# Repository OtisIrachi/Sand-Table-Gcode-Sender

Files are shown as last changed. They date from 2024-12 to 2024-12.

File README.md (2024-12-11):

****************************************************************************************************
Sand Table Gcode Sender

 Completed Table

This project is a mashup of several programs to create yet another version of a COREXY Sand Table.
My frustration was in the complexity of other projects, although done quite well,
but I wanted a simpler approach.  
Utilizes an ESP32 D1 Mini module as a "gcode sender" via the secondary Serial TX-Rx Port (pins 16 and 17)
to a modified Grbl CNC Shield UNO controller.
A logic level shifter board is needed to connect the 3.3V TX and RX from the ESP32 to the
5.0V TX and RX on the CNC Shield.
All files from this project are included.

Board Mount

Basic components are:

525mm x 525mm CoreXY Table.

Grbl CNC Shield and Arduino UNO for stepper motor controller.

TMC2209 Stepper Drivers for quiet operation.

ESP32 and SDCard module for sending gcode programs to the grbl stepper motor controller.

cnc shield and esp32 sender

****************************************************************************************************

The original STL Files are referenced from https://www.instructables.com/Easily-Build-a-MACHINE-THAT-DESTROYS-WHAT-IT-CREAT/  project.

The STL Files in this project folder were modified and used here:  

https://github.com/OtisIrachi/Sand-Table-Gcode-Sender/tree/main/Kinetic%20STL%20Files

The grbl source code is a modified version of the original V1.1 grbl source code found here:

https://github.com/OtisIrachi/Sand-Table-Gcode-Sender/tree/main/grbl_Modified

That source code is attached in this project.  All you need to do is load it onto your Arduino UNO.
Mostly it is changed for IO config and a Baud rate of 9600 in order to keep up with
motor moves and grbl handshaking.

****************************************************************************************************

The sand patterns were created with:

[https://github.com/markroland/sand-table-pattern-maker.](https://github.com/OtisIrachi/Sand-Table-Gcode-Sender/tree/main/SandPatternMaker525)

You may also use sandify.org:

https://sandify.org/

Each .gcode file is manually edited at beginning and the end for simplicity in the gsender coding. 

All comments created by Sand Table Maker or sandify.org
are deleted and an Fxxxx speed command is added to the first G1 line, and an "M2"
command at the end of each gcode file.

I modified the "env.js in the "SandPatternMaker525\assets\js" folder to match the 
dimensions of my sand table, roughly 525mm x 525mm.
Run the SandPatternMaker525 program by clicking on the "index.html" file.  It runs in your browser.

ex: 

G1 X5.000 Y5.000 F6000

G1 X12.728 Y0.000

G1 X0.000 Y12.728

G1 X0.000 Y25.456.....

M2

****************************************************************************************************
Table Lighting.

The LED Strip Controller uses an ESP8266 D1 Mini Module,  
a 30 LED/meter strip, 
and a Rotary Encoder Module with Push Button.

https://github.com/OtisIrachi/Sand-Table-Gcode-Sender/tree/main/ESPEncoderNeopixel.
LED Strip Controller

****************************************************************************************************

Wiring and Schematics for this project found here: 

https://github.com/OtisIrachi/Sand-Table-Gcode-Sender/tree/main/Schematics

****************************************************************************************************

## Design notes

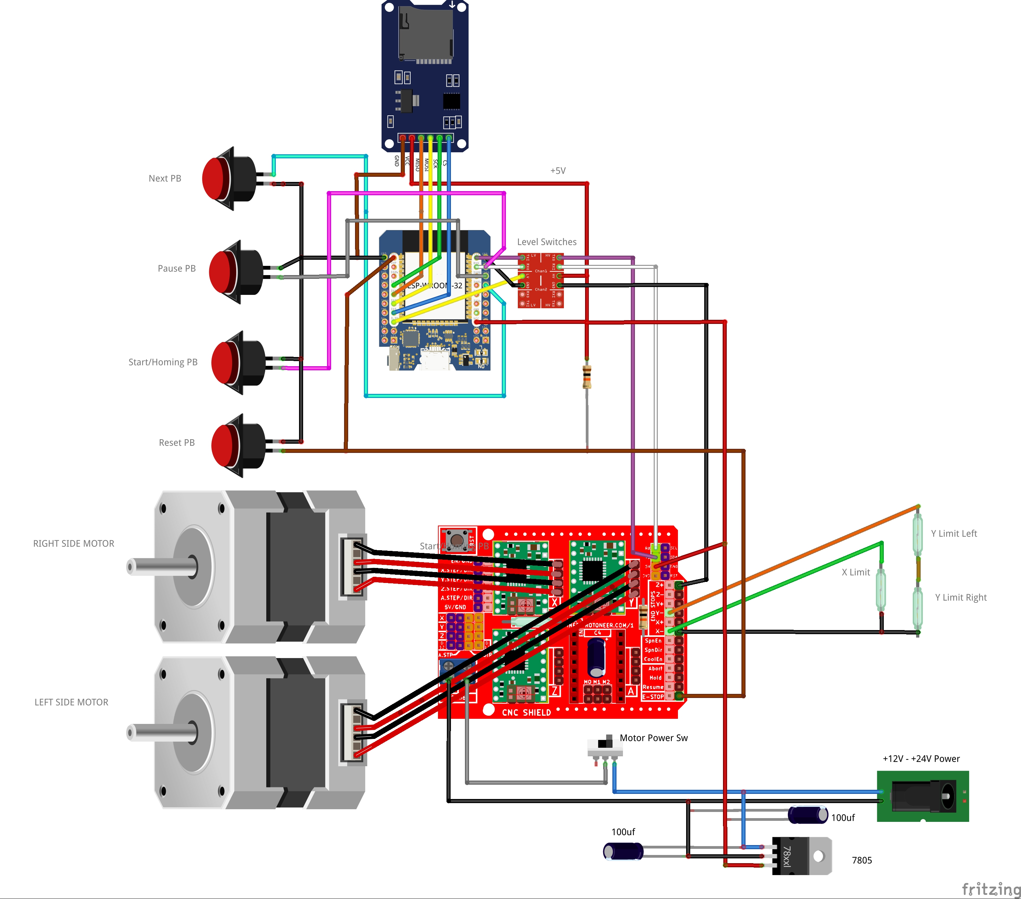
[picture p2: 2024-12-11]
Schematics/GcodeSenderESP32_Fritz.jpg

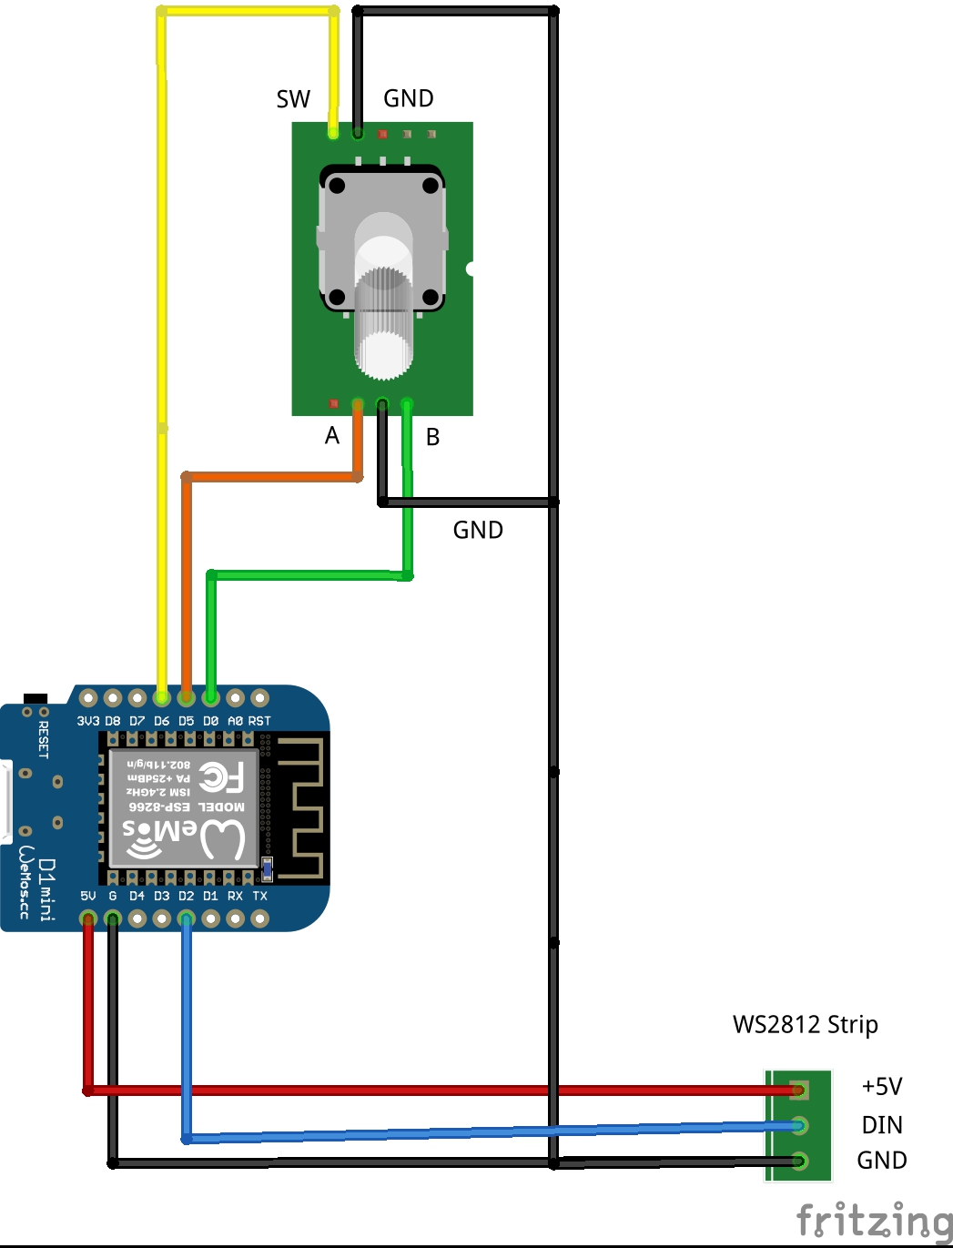
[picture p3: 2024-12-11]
Schematics/ESPEncoderNeopixel_Fritz.jpg

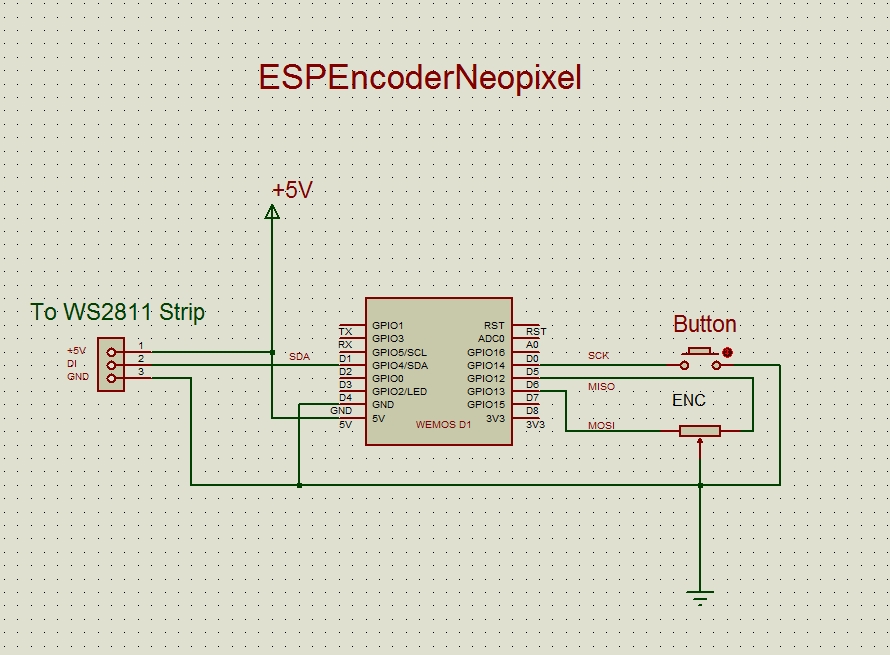
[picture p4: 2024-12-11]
Schematics/LED Strip Controller.jpg

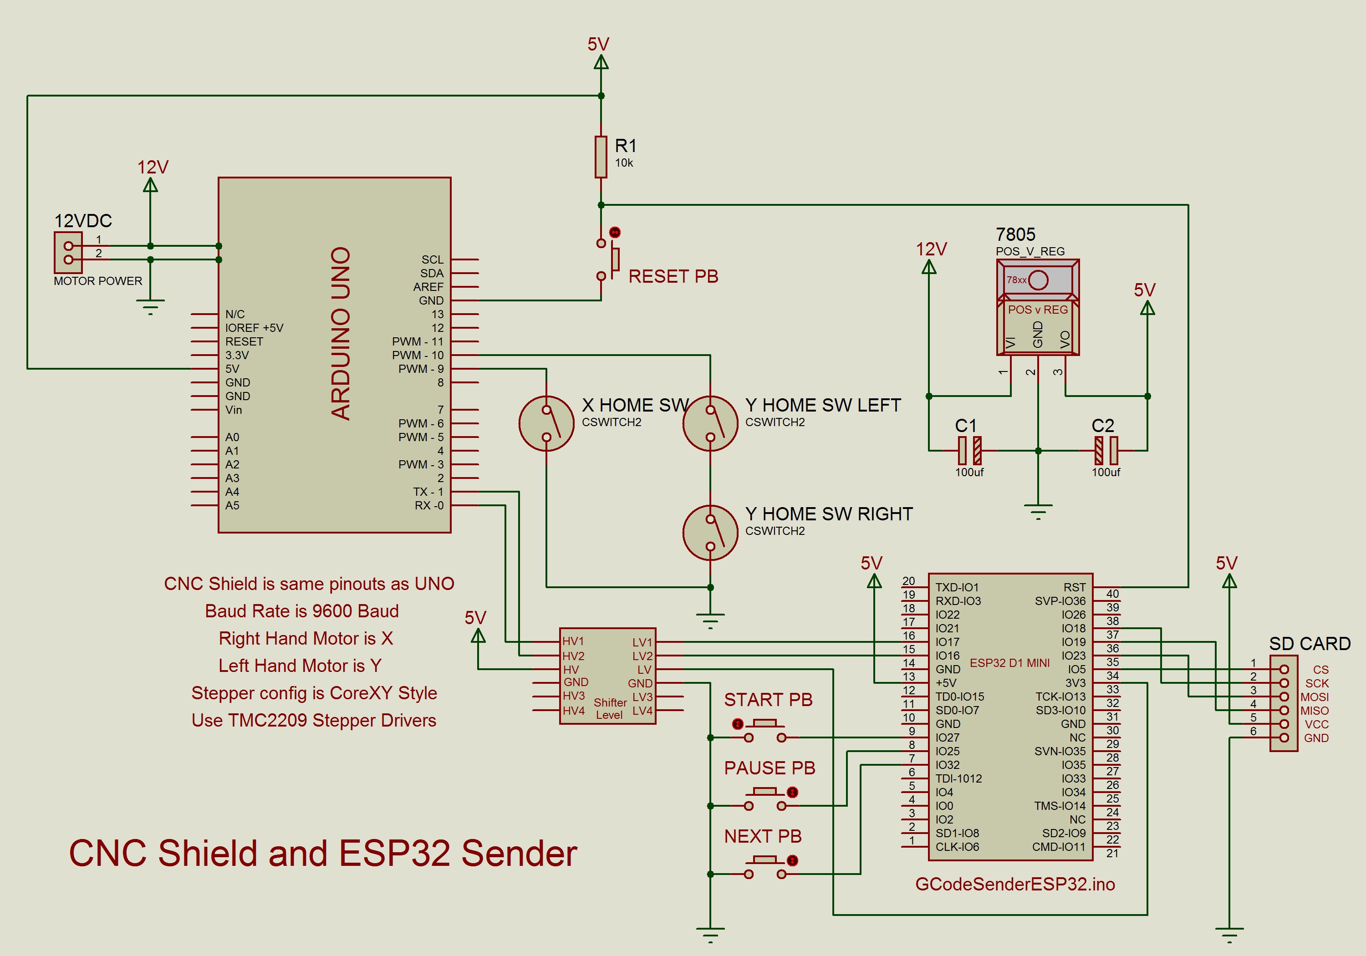
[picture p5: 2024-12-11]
Schematics/cnc shield and esp32 sender.jpg

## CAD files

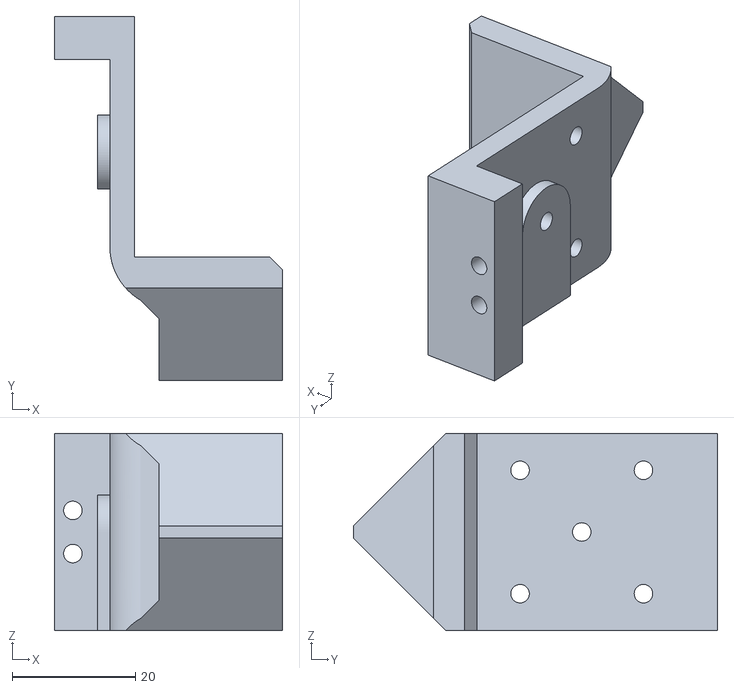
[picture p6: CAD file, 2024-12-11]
Kinetic STL Files/MagnetMount.stl
37.0 x 59.0 x 32.0

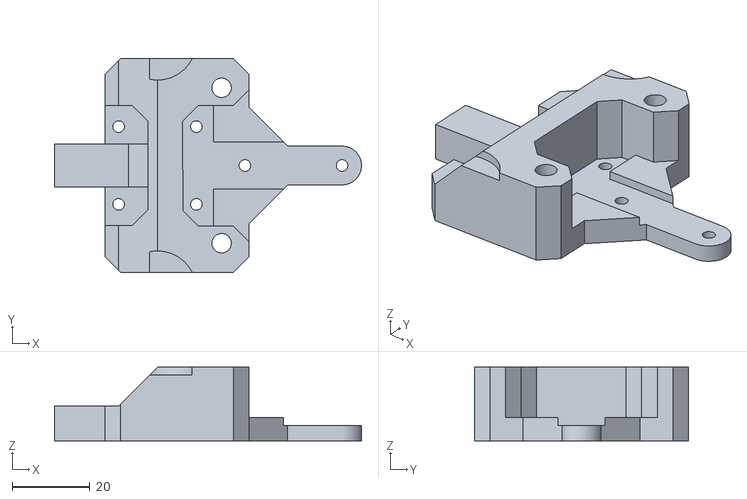
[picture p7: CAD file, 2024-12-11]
Kinetic STL Files/X-CarriageMount.stl
79.0 x 55.0 x 19.0

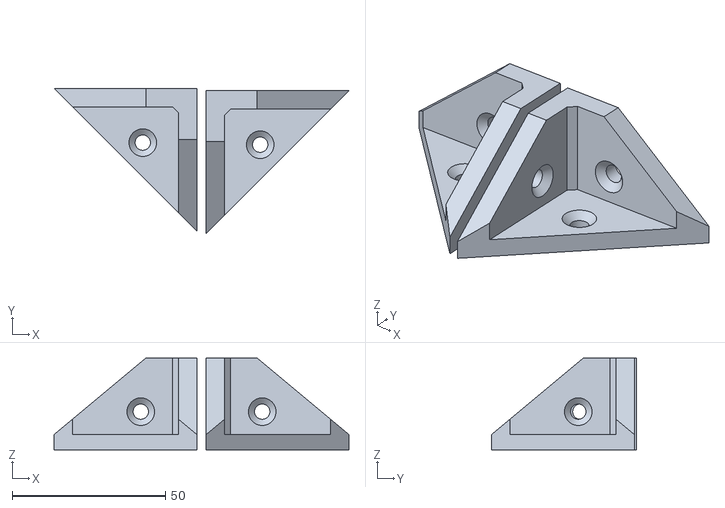
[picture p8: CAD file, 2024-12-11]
Kinetic STL Files/Corner Brackets Pair.stl
96.3 x 47.4 x 30.0

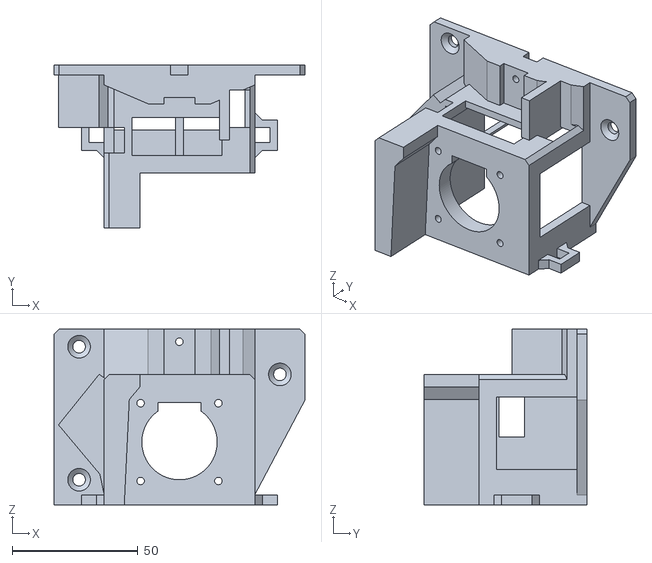
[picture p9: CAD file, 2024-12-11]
Kinetic STL Files/MotorBaseRight.stl
100.0 x 65.0 x 70.0

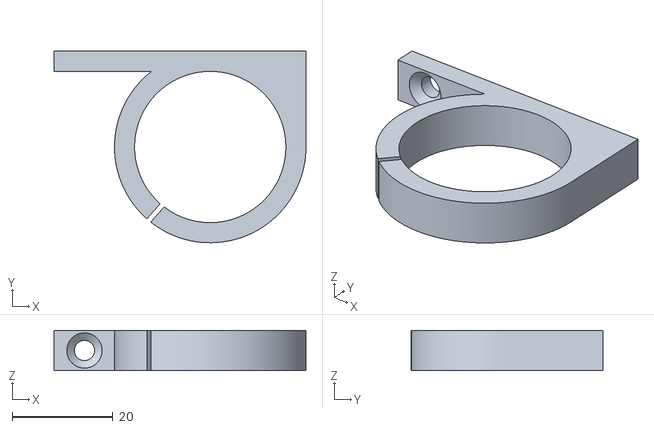
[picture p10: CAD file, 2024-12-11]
Kinetic STL Files/WireLoop.stl
50.0 x 38.0 x 8.00

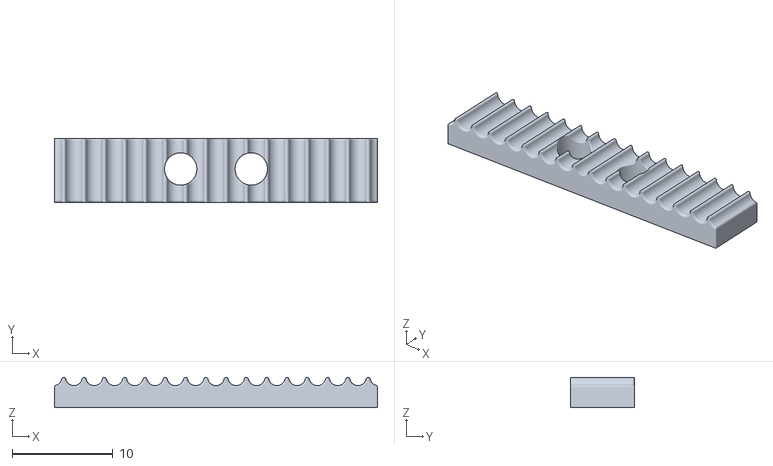
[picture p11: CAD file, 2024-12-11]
Kinetic STL Files/BeltGrip.stl
32.0 x 6.30 x 3.00

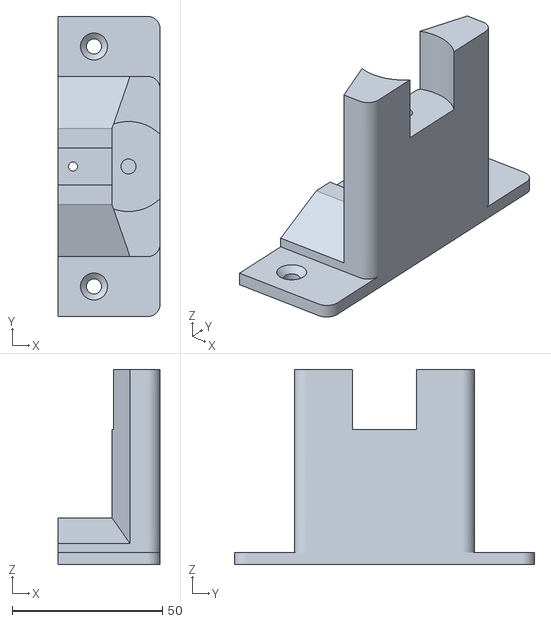
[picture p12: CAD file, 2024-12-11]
Kinetic STL Files/IdleSupport.stl
34.0 x 100.0 x 65.0

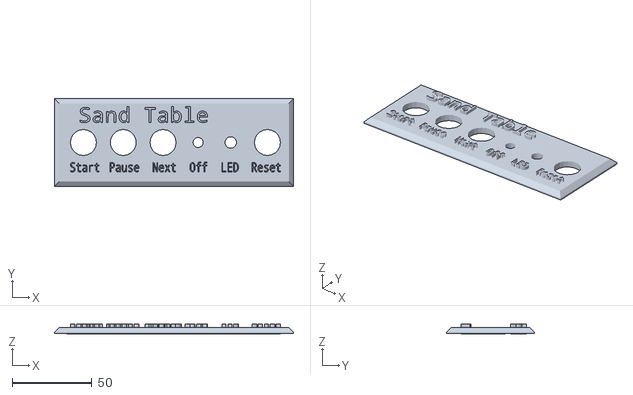
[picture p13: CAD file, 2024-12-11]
Kinetic STL Files/My Control Panel.stl
150.0 x 55.0 x 6.00

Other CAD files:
Kinetic STL Files/MotorBaseLeft.stl

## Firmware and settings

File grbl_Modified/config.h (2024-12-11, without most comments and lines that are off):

#define config_h
#include "grbl.h" // For Arduino IDE compatibility.
#define DEFAULTS_DIYM_SAND_TABLE
#define CPU_MAP_ATMEGA328P // Arduino Uno CPU
#define BAUD_RATE 9600
#define CMD_RESET 0x18 // ctrl-x.
#define CMD_STATUS_REPORT '?'
#define CMD_CYCLE_START '~'
#define CMD_FEED_HOLD '!'
#define CMD_SAFETY_DOOR 0x84
#define CMD_JOG_CANCEL  0x85
#define CMD_DEBUG_REPORT 0x86 // Only when DEBUG enabled, sends debug report in '{}' braces.
#define CMD_FEED_OVR_RESET 0x90         // Restores feed override value to 100%.
#define CMD_FEED_OVR_COARSE_PLUS 0x91
#define CMD_FEED_OVR_COARSE_MINUS 0x92
#define CMD_FEED_OVR_FINE_PLUS  0x93
#define CMD_FEED_OVR_FINE_MINUS  0x94
#define CMD_RAPID_OVR_RESET 0x95        // Restores rapid override value to 100%.
#define CMD_RAPID_OVR_MEDIUM 0x96
#define CMD_RAPID_OVR_LOW 0x97
#define CMD_SPINDLE_OVR_RESET 0x99      // Restores spindle override value to 100%.
#define CMD_SPINDLE_OVR_COARSE_PLUS 0x9A
#define CMD_SPINDLE_OVR_COARSE_MINUS 0x9B
#define CMD_SPINDLE_OVR_FINE_PLUS 0x9C
#define CMD_SPINDLE_OVR_FINE_MINUS 0x9D
#define CMD_SPINDLE_OVR_STOP 0x9E
#define CMD_COOLANT_FLOOD_OVR_TOGGLE 0xA0
#define CMD_COOLANT_MIST_OVR_TOGGLE 0xA1
 #define HOMING_CYCLE_0 (1<<Y_AXIS)  // COREXY COMPATIBLE: First home Y
 #define HOMING_CYCLE_1 (1<<X_AXIS)  // COREXY COMPATIBLE: Then home X
#define N_HOMING_LOCATE_CYCLE 1 // Integer (1-128)
#define HOMING_FORCE_SET_ORIGIN // Uncomment to enable.
#define N_STARTUP_LINE 2 // Integer (1-2)
#define N_DECIMAL_COORDVALUE_INCH 4 // Coordinate or position value in inches
#define N_DECIMAL_COORDVALUE_MM   3 // Coordinate or position value in mm
#define N_DECIMAL_RATEVALUE_INCH  1 // Rate or velocity value in in/min
#define N_DECIMAL_RATEVALUE_MM    0 // Rate or velocity value in mm/min
#define N_DECIMAL_SETTINGVALUE    3 // Decimals for floating point setting values
#define N_DECIMAL_RPMVALUE        0 // RPM value in rotations per min.
#define MESSAGE_PROBE_COORDINATES // Enabled by default. Comment to disable.
#define SAFETY_DOOR_SPINDLE_DELAY 4.0 // Float (seconds)
#define SAFETY_DOOR_COOLANT_DELAY 1.0 // Float (seconds)
 #define COREXY // Default disabled. Uncomment to enable.
#define CHECK_LIMITS_AT_INIT
#define DEFAULT_FEED_OVERRIDE           100 // 100%. Don't change this value.
#define MAX_FEED_RATE_OVERRIDE          200 // Percent of programmed feed rate (100-255). Usually 120% or 200%
#define MIN_FEED_RATE_OVERRIDE           10 // Percent of programmed feed rate (1-100). Usually 50% or 1%
#define FEED_OVERRIDE_COARSE_INCREMENT   10 // (1-99). Usually 10%.
#define FEED_OVERRIDE_FINE_INCREMENT      1 // (1-99). Usually 1%.
#define DEFAULT_RAPID_OVERRIDE  100 // 100%. Don't change this value.
#define RAPID_OVERRIDE_MEDIUM    50 // Percent of rapid (1-99). Usually 50%.
#define RAPID_OVERRIDE_LOW       25 // Percent of rapid (1-99). Usually 25%.
#define DEFAULT_SPINDLE_SPEED_OVERRIDE    100 // 100%. Don't change this value.
#define MAX_SPINDLE_SPEED_OVERRIDE        200 // Percent of programmed spindle speed (100-255). Usually 200%.
#define MIN_SPINDLE_SPEED_OVERRIDE         10 // Percent of programmed spindle speed (1-100). Usually 10%.
#define SPINDLE_OVERRIDE_COARSE_INCREMENT  10 // (1-99). Usually 10%.
#define SPINDLE_OVERRIDE_FINE_INCREMENT     1 // (1-99). Usually 1%.
#define RESTORE_OVERRIDES_AFTER_PROGRAM_END // Default enabled. Comment to disable.
#define REPORT_FIELD_BUFFER_STATE // Default enabled. Comment to disable.
#define REPORT_FIELD_PIN_STATE // Default enabled. Comment to disable.
#define REPORT_FIELD_CURRENT_FEED_SPEED // Default enabled. Comment to disable.
#define REPORT_FIELD_WORK_COORD_OFFSET // Default enabled. Comment to disable.
#define REPORT_FIELD_OVERRIDES // Default enabled. Comment to disable.
#define REPORT_FIELD_LINE_NUMBERS // Default enabled. Comment to disable.
#define REPORT_OVR_REFRESH_BUSY_COUNT 20  // (1-255)
#define REPORT_OVR_REFRESH_IDLE_COUNT 10  // (1-255) Must be less than or equal to the busy count
#define REPORT_WCO_REFRESH_BUSY_COUNT 30  // (2-255)
#define REPORT_WCO_REFRESH_IDLE_COUNT 10  // (2-255) Must be less than or equal to the busy count
#define ACCELERATION_TICKS_PER_SECOND 100
#define ADAPTIVE_MULTI_AXIS_STEP_SMOOTHING  // Default enabled. Comment to disable.
#define TOOL_LENGTH_OFFSET_AXIS Z_AXIS // Default z-axis. Valid values are X_AXIS, Y_AXIS, or Z_AXIS.
#define VARIABLE_SPINDLE // Default enabled. Comment to disable.
#define MINIMUM_JUNCTION_SPEED 0.0 // (mm/min)
#define MINIMUM_FEED_RATE 1.0 // (mm/min)
#define N_ARC_CORRECTION 12 // Integer (1-255)
#define ARC_ANGULAR_TRAVEL_EPSILON 5E-7 // Float (radians)
#define DWELL_TIME_STEP 50 // Integer (1-255) (milliseconds)
#define ENABLE_RESTORE_EEPROM_WIPE_ALL         // '$RST=*' Default enabled. Comment to disable.
#define ENABLE_RESTORE_EEPROM_DEFAULT_SETTINGS // '$RST=$' Default enabled. Comment to disable.
#define ENABLE_RESTORE_EEPROM_CLEAR_PARAMETERS // '$RST=#' Default enabled. Comment to disable.
#define ENABLE_BUILD_INFO_WRITE_COMMAND // '$I=' Default enabled. Comment to disable.
#define FORCE_BUFFER_SYNC_DURING_EEPROM_WRITE // Default enabled. Comment to disable.
#define FORCE_BUFFER_SYNC_DURING_WCO_CHANGE // Default enabled. Comment to disable.
#define PARKING_AXIS Z_AXIS // Define which axis that performs the parking motion
#define PARKING_TARGET -5.0 // Parking axis target. In mm, as machine coordinate [-max_travel,0].
#define PARKING_RATE 500.0 // Parking fast rate after pull-out in mm/min.
#define PARKING_PULLOUT_RATE 100.0 // Pull-out/plunge slow feed rate in mm/min.
#define PARKING_PULLOUT_INCREMENT 5.0 // Spindle pull-out and plunge distance in mm. Incremental distance.
#define DISABLE_LASER_DURING_HOLD // Default enabled. Comment to disable.
#define N_PIECES 4  // Integer (1-4). Number of piecewise lines used in script solution.
#define RPM_MAX  11686.4  // Max RPM of model. $30 > RPM_MAX will be limited to RPM_MAX.
#define RPM_MIN  202.5    // Min RPM of model. $31 < RPM_MIN will be limited to RPM_MIN.
#define RPM_POINT12  6145.4  // Used N_PIECES >=2. Junction point between lines 1 and 2.
#define RPM_POINT23  9627.8  // Used N_PIECES >=3. Junction point between lines 2 and 3.
#define RPM_POINT34  10813.9 // Used N_PIECES = 4. Junction point between lines 3 and 4.
#define RPM_LINE_A1  3.197101e-03  // Used N_PIECES >=1. A and B constants of line 1.
#define RPM_LINE_B1  -3.526076e-1
#define RPM_LINE_A2  1.722950e-2   // Used N_PIECES >=2. A and B constants of line 2.
#define RPM_LINE_B2  8.588176e+01
#define RPM_LINE_A3  5.901518e-02  // Used N_PIECES >=3. A and B constants of line 3.
#define RPM_LINE_B3  4.881851e+02
#define RPM_LINE_A4  1.203413e-01  // Used N_PIECES = 4. A and B constants of line 4.
#define RPM_LINE_B4  1.151360e+03
#define DUAL_AXIS_SELECT  X_AXIS  // Must be either X_AXIS or Y_AXIS
#define DUAL_AXIS_HOMING_FAIL_AXIS_LENGTH_PERCENT  5.0  // Float (percent)
#define DUAL_AXIS_HOMING_FAIL_DISTANCE_MAX  25.0  // Float (mm)
#define DUAL_AXIS_HOMING_FAIL_DISTANCE_MIN  2.5  // Float (mm)
#define DUAL_AXIS_CONFIG_PROTONEER_V3_51    // Uncomment to select. Comment other configs.

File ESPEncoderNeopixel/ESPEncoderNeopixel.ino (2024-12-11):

//************************************************************************************************
// ESPEncoderNeopixel.ino
// Uses an ESP CPU and an Encode with switch to run through LED programs.
//
// Button = SCK
// Yellow = MOSI
// Orange = MISO 
// Led Strip IO33
//
//
// RCI 10-30-2024
//************************************************************************************************
#include <AiEsp32RotaryEncoder.h>
#include <Adafruit_NeoPixel.h>
#include "WS2811_Patterns.h"

#define pinPullups 0    // 0 = Pullup, 1 = PullDown

#if defined(ESP32)
#define ROTARY_ENCODER_A_PIN      25  // MISO
#define ROTARY_ENCODER_B_PIN      27  // MOSI
#define ROTARY_ENCODER_BUTTON_PIN 26  // SCK
#endif

#if defined(ESP8266)
#define ROTARY_ENCODER_A_PIN      13  // MISO
#define ROTARY_ENCODER_B_PIN      12  // MOSI
#define ROTARY_ENCODER_BUTTON_PIN 14  // SCK
#endif

#define ROTARY_ENCODER_STEPS 4


unsigned long time_now = 0;
int brightness = 127;
int progNum = 0;
//extern bool buttonPressedFlag = 0;

AiEsp32RotaryEncoder rotaryEncoder = AiEsp32RotaryEncoder(ROTARY_ENCODER_A_PIN, ROTARY_ENCODER_B_PIN, 
                                     ROTARY_ENCODER_BUTTON_PIN, -1, ROTARY_ENCODER_STEPS, pinPullups);
//******************************************************************************************
void IRAM_ATTR readEncoderISR()
{
    rotaryEncoder.readEncoder_ISR();
}
//************************************************************************************************
// Delay (loops) Milliseconds
void delayms(int loops) 
{
    time_now = millis();
    
    while(millis() < time_now + loops)
      {
      brightness = rotaryEncoder.readEncoder();
      strip.setBrightness(brightness);
      //Serial.println(rotaryEncoder.readEncoder());

      if (rotaryEncoder.isEncoderButtonClicked())
        {
        //Serial.println("button pressed");
        buttonPressedFlag = 1;
        progNum++;
        //break;
        }
      delay(1);   
      } 
           
}
//******************************************************************************************
void setup()
{
    Serial.begin(115200);
    delay(3000);
    pinMode(PIN, OUTPUT);
    
    rotaryEncoder.begin();
    //rotaryEncoder.areEncoderPinsPulldownforEsp32 = false;
    rotaryEncoder.setup(readEncoderISR);
    rotaryEncoder.setBoundaries(0, 255, false); 
    rotaryEncoder.setAcceleration(250);
    brightness = rotaryEncoder.readEncoder();
    progNum = 0;
   
}
//******************************************************************************************
void loop()
{

    
    if(progNum > 11) progNum = 0;

    switch(progNum)
       {
       case 0:
       SolidColor(wht, 1);
       delayms(1);
       break;
       //****************************
       case 1:
       SolidColor(rde, 1);
       delayms(1);
       break;
       //****************************
       case 2:
       SolidColor(grn, 1);
       delayms(1);
       break;
       //****************************
       case 3:
       SolidColor(blu, 1);
       delayms(1);
       break;
       //****************************
       case 4:
       SolidColor(yellow, 1);
       delayms(1);
       break;
       //****************************
       case 5:
       SolidColor(magenta, 1);
       delayms(1);
       break;
       //****************************
       case 6:
       SolidColor(cyan, 1);
       delayms(1);
       break;
       //****************************
       case 7:

       //theaterChaseRainbowFor(3, 1, 150); //  fixed rainbow color with chased position
       theaterChaseRainbow(3, 1, 150); // skipt, cycles, wait

       break;
       //****************************
       case 8:

       rainbowStrip(25);   // delay

       break;
       //****************************
       case 9:

       rainbowCycleFor(1, 25); 

       break;
       //****************************
       case 10:
       MultiCometRev(wht, 15, 1, 100);  // skipt, cycles, wait 
       delayms(1);
       break;
       //****************************
       case 11:

       RandomColorStrip(2, 1, 350); 

       break;                     
       //****************************
       default:

       break;       
       }



      


}
//******************************************************************************************

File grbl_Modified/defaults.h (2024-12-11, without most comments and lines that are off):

#ifdef DEFAULTS_GENERIC
  #define DEFAULT_X_STEPS_PER_MM 250.0
  #define DEFAULT_Y_STEPS_PER_MM 250.0
  #define DEFAULT_Z_STEPS_PER_MM 250.0
  #define DEFAULT_X_MAX_RATE 500.0 // mm/min
  #define DEFAULT_Y_MAX_RATE 500.0 // mm/min
  #define DEFAULT_Z_MAX_RATE 500.0 // mm/min
  #define DEFAULT_X_ACCELERATION (10.0*60*60) // 10*60*60 mm/min^2 = 10 mm/sec^2
  #define DEFAULT_Y_ACCELERATION (10.0*60*60) // 10*60*60 mm/min^2 = 10 mm/sec^2
  #define DEFAULT_Z_ACCELERATION (10.0*60*60) // 10*60*60 mm/min^2 = 10 mm/sec^2
  #define DEFAULT_X_MAX_TRAVEL 200.0 // mm NOTE: Must be a positive value.
  #define DEFAULT_Y_MAX_TRAVEL 200.0 // mm NOTE: Must be a positive value.
  #define DEFAULT_Z_MAX_TRAVEL 200.0 // mm NOTE: Must be a positive value.
  #define DEFAULT_SPINDLE_RPM_MAX 1000.0 // rpm
  #define DEFAULT_SPINDLE_RPM_MIN 0.0 // rpm
  #define DEFAULT_STEP_PULSE_MICROSECONDS 10
  #define DEFAULT_STEPPING_INVERT_MASK 0
  #define DEFAULT_DIRECTION_INVERT_MASK 0
  #define DEFAULT_STEPPER_IDLE_LOCK_TIME 25 // msec (0-254, 255 keeps steppers enabled)
  #define DEFAULT_STATUS_REPORT_MASK 1 // MPos enabled
  #define DEFAULT_JUNCTION_DEVIATION 0.01 // mm
  #define DEFAULT_ARC_TOLERANCE 0.002 // mm
  #define DEFAULT_REPORT_INCHES 0 // false
  #define DEFAULT_INVERT_ST_ENABLE 0 // false
  #define DEFAULT_INVERT_LIMIT_PINS 0 // false
  #define DEFAULT_SOFT_LIMIT_ENABLE 0 // false
  #define DEFAULT_HARD_LIMIT_ENABLE 0  // false
  #define DEFAULT_INVERT_PROBE_PIN 0 // false
  #define DEFAULT_LASER_MODE 0 // false
  #define DEFAULT_HOMING_ENABLE 0  // false
  #define DEFAULT_HOMING_DIR_MASK 0 // move positive dir
  #define DEFAULT_HOMING_FEED_RATE 25.0 // mm/min
  #define DEFAULT_HOMING_SEEK_RATE 500.0 // mm/min
  #define DEFAULT_HOMING_DEBOUNCE_DELAY 250 // msec (0-65k)
  #define DEFAULT_HOMING_PULLOFF 1.0 // mm
#endif
  #define DEFAULT_X_STEPS_PER_MM 80.0
  #define DEFAULT_Y_STEPS_PER_MM 80.0
  #define DEFAULT_Z_STEPS_PER_MM 250.0
  #define DEFAULT_X_MAX_RATE 5000.0 // mm/min
  #define DEFAULT_Y_MAX_RATE 5000.0 // mm/min
  #define DEFAULT_Z_MAX_RATE 250.0 // mm/min
  #define DEFAULT_X_ACCELERATION (50.0*60*60) // 10*60*60 mm/min^2 = 10 mm/sec^2
  #define DEFAULT_Y_ACCELERATION (50.0*60*60) // 10*60*60 mm/min^2 = 10 mm/sec^2
  #define DEFAULT_Z_ACCELERATION (10.0*60*60) // 10*60*60 mm/min^2 = 10 mm/sec^2
  #define DEFAULT_X_MAX_TRAVEL 500.0 // mm NOTE: Must be a positive value.
  #define DEFAULT_Y_MAX_TRAVEL 500.0 // mm NOTE: Must be a positive value.
  #define DEFAULT_Z_MAX_TRAVEL 200.0 // mm NOTE: Must be a positive value.
  #define DEFAULT_SPINDLE_RPM_MAX 1000.0 // rpm
  #define DEFAULT_SPINDLE_RPM_MIN 0.0 // rpm
  #define DEFAULT_STEP_PULSE_MICROSECONDS 10
  #define DEFAULT_STEPPING_INVERT_MASK 0
  #define DEFAULT_DIRECTION_INVERT_MASK 0
  #define DEFAULT_STEPPER_IDLE_LOCK_TIME 25 // msec (0-254, 255 keeps steppers enabled)
  #define DEFAULT_STATUS_REPORT_MASK 1 // MPos enabled
  #define DEFAULT_JUNCTION_DEVIATION 0.01 // mm
  #define DEFAULT_ARC_TOLERANCE 0.002 // mm
  #define DEFAULT_REPORT_INCHES 0 // false
  #define DEFAULT_INVERT_ST_ENABLE 0 // false
  #define DEFAULT_INVERT_LIMIT_PINS 0 // false
  #define DEFAULT_SOFT_LIMIT_ENABLE 0 // true
  #define DEFAULT_HARD_LIMIT_ENABLE 1  // true
  #define DEFAULT_INVERT_PROBE_PIN 0 // false
  #define DEFAULT_LASER_MODE 0 // false
  #define DEFAULT_HOMING_ENABLE 1  // true
  #define DEFAULT_HOMING_DIR_MASK 3 // move positive dir
  #define DEFAULT_HOMING_FEED_RATE 25.0 // mm/min
  #define DEFAULT_HOMING_SEEK_RATE 1500.0 // mm/min
  #define DEFAULT_HOMING_DEBOUNCE_DELAY 250 // msec (0-65k)
  #define DEFAULT_HOMING_PULLOFF 2.0 // mm
#ifdef DEFAULTS_SHERLINE_5400
  #define MICROSTEPS 2
  #define STEPS_PER_REV 200.0
  #define MM_PER_REV (0.050*MM_PER_INCH) // 0.050 inch/rev leadscrew
  #define DEFAULT_X_STEPS_PER_MM (STEPS_PER_REV*MICROSTEPS/MM_PER_REV)
  #define DEFAULT_Y_STEPS_PER_MM (STEPS_PER_REV*MICROSTEPS/MM_PER_REV)
  #define DEFAULT_Z_STEPS_PER_MM (STEPS_PER_REV*MICROSTEPS/MM_PER_REV)
  #define DEFAULT_X_MAX_RATE 635.0 // mm/min (25 ipm)
  #define DEFAULT_Y_MAX_RATE 635.0 // mm/min
  #define DEFAULT_Z_MAX_RATE 635.0 // mm/min
  #define DEFAULT_X_ACCELERATION (50.0*60*60) // 50*60*60 mm/min^2 = 50 mm/sec^2
  #define DEFAULT_Y_ACCELERATION (50.0*60*60) // 50*60*60 mm/min^2 = 50 mm/sec^2
  #define DEFAULT_Z_ACCELERATION (50.0*60*60) // 50*60*60 mm/min^2 = 50 mm/sec^2
  #define DEFAULT_X_MAX_TRAVEL 225.0 // mm NOTE: Must be a positive value.
  #define DEFAULT_Y_MAX_TRAVEL 125.0 // mm NOTE: Must be a positive value.
  #define DEFAULT_Z_MAX_TRAVEL 170.0 // mm NOTE: Must be a positive value.
  #define DEFAULT_SPINDLE_RPM_MAX 2800.0 // rpm
  #define DEFAULT_SPINDLE_RPM_MIN 0.0 // rpm
  #define DEFAULT_STEP_PULSE_MICROSECONDS 10
  #define DEFAULT_STEPPING_INVERT_MASK 0
  #define DEFAULT_DIRECTION_INVERT_MASK ((1<<Y_AXIS)|(1<<Z_AXIS))
  #define DEFAULT_STEPPER_IDLE_LOCK_TIME 25 // msec (0-254, 255 keeps steppers enabled)
  #define DEFAULT_STATUS_REPORT_MASK 1 // MPos enabled
  #define DEFAULT_JUNCTION_DEVIATION 0.01 // mm
  #define DEFAULT_ARC_TOLERANCE 0.002 // mm
  #define DEFAULT_REPORT_INCHES 0 // true
  #define DEFAULT_INVERT_ST_ENABLE 0 // false
  #define DEFAULT_INVERT_LIMIT_PINS 0 // false
  #define DEFAULT_SOFT_LIMIT_ENABLE 0 // false
  #define DEFAULT_HARD_LIMIT_ENABLE 0  // false
  #define DEFAULT_INVERT_PROBE_PIN 0 // false
  #define DEFAULT_LASER_MODE 0 // false
  #define DEFAULT_HOMING_ENABLE 0  // false
  #define DEFAULT_HOMING_DIR_MASK 0 // move positive dir
  #define DEFAULT_HOMING_FEED_RATE 50.0 // mm/min
  #define DEFAULT_HOMING_SEEK_RATE 635.0 // mm/min
  #define DEFAULT_HOMING_DEBOUNCE_DELAY 250 // msec (0-65k)
  #define DEFAULT_HOMING_PULLOFF 1.0 // mm
#endif
#ifdef DEFAULTS_POCKETNC_FR4
  #define DEFAULT_X_STEPS_PER_MM 800.0
  #define DEFAULT_Y_STEPS_PER_MM 800.0
  #define DEFAULT_Z_STEPS_PER_MM 800.0
  #define DEFAULT_X_MAX_RATE 300.0 // mm/min
  #define DEFAULT_Y_MAX_RATE 300.0 // mm/min
  #define DEFAULT_Z_MAX_RATE 300.0 // mm/min
  #define DEFAULT_X_ACCELERATION (30.0*60*60) // 15*60*60 mm/min^2 = 15 mm/sec^2
  #define DEFAULT_Y_ACCELERATION (30.0*60*60) // 15*60*60 mm/min^2 = 15 mm/sec^2
  #define DEFAULT_Z_ACCELERATION (30.0*60*60) // 15*60*60 mm/min^2 = 15 mm/sec^2
  #define DEFAULT_X_MAX_TRAVEL 225.0 // mm NOTE: Must be a positive value.
  #define DEFAULT_Y_MAX_TRAVEL 125.0 // mm NOTE: Must be a positive value.
  #define DEFAULT_Z_MAX_TRAVEL 170.0 // mm NOTE: Must be a positive value.
  #define DEFAULT_SPINDLE_RPM_MAX 7000.0 // rpm
  #define DEFAULT_SPINDLE_RPM_MIN 0.0 // rpm
  #define DEFAULT_STEP_PULSE_MICROSECONDS 10
  #define DEFAULT_STEPPING_INVERT_MASK 0
  #define DEFAULT_DIRECTION_INVERT_MASK ((1<<Y_AXIS)|(1<<Z_AXIS))
  #define DEFAULT_STEPPER_IDLE_LOCK_TIME 250 // msec (0-254, 255 keeps steppers enabled)
  #define DEFAULT_STATUS_REPORT_MASK 3 // WPos enabled
  #define DEFAULT_JUNCTION_DEVIATION 0.01 // mm
  #define DEFAULT_ARC_TOLERANCE 0.002 // mm
  #define DEFAULT_REPORT_INCHES 0 // false
  #define DEFAULT_INVERT_ST_ENABLE 1 // false
  #define DEFAULT_INVERT_LIMIT_PINS 0 // false
  #define DEFAULT_SOFT_LIMIT_ENABLE 0 // false
  #define DEFAULT_HARD_LIMIT_ENABLE 0  // false
  #define DEFAULT_INVERT_PROBE_PIN 0 // false
  #define DEFAULT_LASER_MODE 0 // false
  #define DEFAULT_HOMING_ENABLE 1  // false
  #define DEFAULT_HOMING_DIR_MASK 1 // move positive dir
  #define DEFAULT_HOMING_FEED_RATE 100.0 // mm/min
  #define DEFAULT_HOMING_SEEK_RATE 300.0 // mm/min
  #define DEFAULT_HOMING_DEBOUNCE_DELAY 250 // msec (0-65k)
  #define DEFAULT_HOMING_PULLOFF 3.0 // mm
#endif
#ifdef DEFAULTS_SHAPEOKO
  #define MICROSTEPS_XY 8
  #define STEP_REVS_XY 400
  #define MM_PER_REV_XY (0.08*18*MM_PER_INCH) // 0.08 in belt pitch, 18 pulley teeth
  #define MICROSTEPS_Z 2
  #define STEP_REVS_Z 400
  #define MM_PER_REV_Z 1.250 // 1.25 mm/rev leadscrew
  #define DEFAULT_X_STEPS_PER_MM (MICROSTEPS_XY*STEP_REVS_XY/MM_PER_REV_XY)
  #define DEFAULT_Y_STEPS_PER_MM (MICROSTEPS_XY*STEP_REVS_XY/MM_PER_REV_XY)
  #define DEFAULT_Z_STEPS_PER_MM (MICROSTEPS_Z*STEP_REVS_Z/MM_PER_REV_Z)
  #define DEFAULT_X_MAX_RATE 1000.0 // mm/min
  #define DEFAULT_Y_MAX_RATE 1000.0 // mm/min
  #define DEFAULT_Z_MAX_RATE 1000.0 // mm/min
  #define DEFAULT_X_ACCELERATION (15.0*60*60) // 15*60*60 mm/min^2 = 15 mm/sec^2
  #define DEFAULT_Y_ACCELERATION (15.0*60*60) // 15*60*60 mm/min^2 = 15 mm/sec^2
  #define DEFAULT_Z_ACCELERATION (15.0*60*60) // 15*60*60 mm/min^2 = 15 mm/sec^2
  #define DEFAULT_X_MAX_TRAVEL 200.0 // mm NOTE: Must be a positive value.
  #define DEFAULT_Y_MAX_TRAVEL 200.0 // mm NOTE: Must be a positive value.
  #define DEFAULT_Z_MAX_TRAVEL 200.0 // mm NOTE: Must be a positive value.
  #define DEFAULT_SPINDLE_RPM_MAX 10000.0 // rpm
  #define DEFAULT_SPINDLE_RPM_MIN 0.0 // rpm
  #define DEFAULT_STEP_PULSE_MICROSECONDS 10
  #define DEFAULT_STEPPING_INVERT_MASK 0
  #define DEFAULT_DIRECTION_INVERT_MASK ((1<<Y_AXIS)|(1<<Z_AXIS))
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

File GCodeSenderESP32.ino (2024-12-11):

//***********************************************************************************
// GCodeSenderESP32.ino
//
// ESP32 Sender:
// This program uses an ESP32 to transmit serial Gcode commands to a standard UNO CNC 
// Shield at 9600 Baud.  I/O consists of a micro SD Card SPI interface, a Start PB, 
// Pause PB, Next PB and Reset PB.  A 4 Channel Logic Level Converter board (Amazon)
// is needed to interface the 3.3V ESP32 RX and TX to the 5V UNO TX and RX. A schematic
// is provided with the project.
//
// GRBL and Sand Table:
// See "Build a Sisyphus MAGIC SAND Coffee Table - DIY Machines" on YouTube 
// for an excellent construction tutorial.
// The CNC Shield is connected to 2 Stepper Motors in a CoreXY Configuration.
// The "grbl" library was modified for 9600 Baud because of the exposed 
// TX and RX wires between the ESP32 and UNO. During contruction, twist 
// the TX and RX wires for added noise immunity.
// Several changes were made to "config.h" and "defaults.h" folders in grbl, 
// therefore use the supplied "grbl" folder for your cnc Shield UNO firmware.
// 
// Sand Patterns:
// Sand Table patterns were created with Sand Table Pattern Maker
// https://github.com/markroland/sand-table-pattern-maker
// Within this project are attached the modified folders for Sand Table Pattern Maker.
// See "SandPatternMaker325" and "SandPatternMaker525".
// You will notice in the \SandPatternMaker525\assets\js folder that env.js has been
// modified for this project.  xmax, ymax, motor speed, ball diameter, and gcode command.
// Changing these variables will customize your Sand Table designs for the size of your project.
// The examples provided are for 325x325mm square and 525x525mm square CoreXY Tables.
// To run the modified folder versions, click on the "index.html" file 
// in the \SandPatternMaker525 or \SandPatternMaker325 directories.
// After you download your newly created pattern, you must modify the .gcode file.
// At the beginning of the file, delate all lines starting with ;
// After the first G1 X--- Y--- line add a space and F2000 (or other speed number)
// to control your pattern speed.
// At the end of the .gcode file, delete the ; line and add an M2 to the last line of the file.
// Change the "const char* gcodeFiles[]" below to match your file listing.
//
// by RCI
// Handshaking programming assisted using ChatGPT.
// 11-22-2024
//***********************************************************************************

#include <SD.h>
#include <HardwareSerial.h>

// Pin definitions
#define PAUSE_BUTTON_PIN 25
#define START_BUTTON_PIN 27
#define NEXT_BUTTON_PIN  32
#define SD_CS_PIN 5

// Serial communication for GRBL
HardwareSerial GRBL(1);
#define GRBL_RX_PIN 16
#define GRBL_TX_PIN 17

// *****  my SD Card Filenames  *****
// ***** Yours will be different *****
// EraseDiagonal325.gcode
// FivePointStar325.gcode
// Gosper325.gcode
// HilbertCurve325.gcode
// PlainCircle325.gcode
// SandTable325.gcode
// SmoothSpiral325.gcode
// Spiral325.gcode
// Spirograph325.gcode
// SquareFrame325.gcode
// TwistedSixPoint325.gcode

// G-code file handling
const char* gcodeFiles[] = {"/SquareFrame325.gcode", "/SmoothSpiral325.gcode", "/Gosper325.gcode", "/HilbertCurve325.gcode", 
                            "/FivePointStar325.gcode", "/Spiral325.gcode"};
File gcodeFile;
int fileIndex = 0;

// Flags and states
bool paused = 0;
bool grblReady = 1;
//***********************************************************************************
// Prompt the user and wait for the start button
void promptAndWaitForStart(const char *message) 
{
    Serial.println(message);
    while (digitalRead(START_BUTTON_PIN) == HIGH) 
       {
       delay(50); 
       }
    delay(500); // Debounce delay
}
//***********************************************************************************
// Perform GRBL homing sequence
void performHoming() 
{
    sendGcode("$H"); // Send homing command
    waitForOk();
    Serial.println("Homing is complete.");
}
//***********************************************************************************
// Send the next G-code file
void sendNextGcodeFile() 
{
    if (fileIndex < sizeof(gcodeFiles) / sizeof(gcodeFiles[0])) 
       {
       gcodeFile = SD.open(gcodeFiles[fileIndex]);
       Serial.print("gcodeFile: "); Serial.println(gcodeFile);
       Serial.print("fileIndex: "); Serial.println(fileIndex);
       Serial.println("");
       if (gcodeFile) 
          {
          Serial.print("Opened: ");
          Serial.println(gcodeFiles[fileIndex]);
          fileIndex++;
          } 
        else 
           {
           Serial.println("Failed to open G-code file.");
           }
        } 
     else 
        {
        Serial.println("All G-code files processed.");
        Serial.println("Do all over again.");
        fileIndex = 0; // Reset to the first file if looping is desired
        paused = 0; 
        handleGcodeExecution();       
        }
}
//***********************************************************************************
// Handle G-code execution
void handleGcodeExecution() 
{
    static String line = "";

    if (gcodeFile && gcodeFile.available()) 
       {
       line = gcodeFile.readStringUntil('\n');
       line.trim();

       if (line.length() > 0 && line[0] != '(') // Skip comments and empty lines
         { 
         if (isGrblReady()) 
            {
            sendGcode(line.c_str());
            }
         }
       } 
    else if (gcodeFile) 
       {
       gcodeFile.close();
       sendNextGcodeFile();
       }
}
//***********************************************************************************
// Check if GRBL is ready
bool isGrblReady() 
{
    GRBL.print("?");
    delay(100); // Allow GRBL to respond
    while (GRBL.available()) 
       {
        String response = GRBL.readStringUntil('\n');
        if (response.startsWith("<Idle") || response.startsWith("<Run")) 
           {
           grblReady = true;
           return true;
           } 
        else if (response.indexOf("error") != -1 || response.startsWith("ALARM")) 
           {
           Serial.println("GRBL Error: " + response);
           grblReady = false;
           return false;
           }
       }
    return false;
}
//***********************************************************************************
// Send a single G-code command only to GRBL
void sendGcodeOnly(const char *command) 
{
    Serial.print("Sending: ");
    Serial.println(command);
    GRBL.println(command);

}
//***********************************************************************************
// Send a single G-code command to GRBL and wait for OK
void sendGcode(const char *command) 
{
    Serial.print("Sending: ");
    Serial.println(command);
    GRBL.println(command);
    waitForOk();
}
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

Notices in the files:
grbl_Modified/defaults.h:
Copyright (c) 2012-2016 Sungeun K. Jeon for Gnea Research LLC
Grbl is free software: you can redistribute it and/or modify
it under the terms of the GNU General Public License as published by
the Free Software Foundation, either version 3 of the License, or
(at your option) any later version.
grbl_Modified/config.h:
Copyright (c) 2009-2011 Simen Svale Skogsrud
